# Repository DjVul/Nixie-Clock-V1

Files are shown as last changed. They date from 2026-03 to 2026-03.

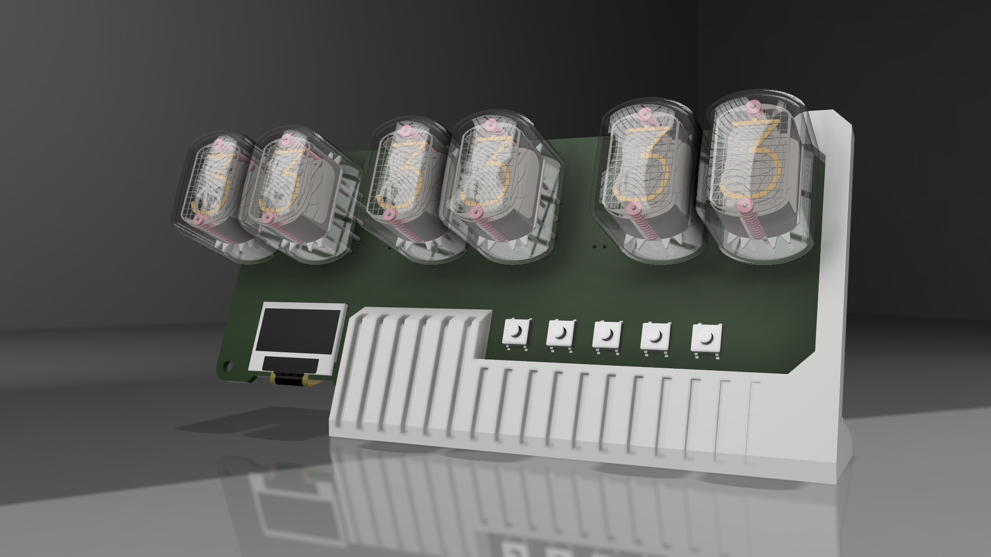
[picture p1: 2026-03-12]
3D Model/Nixie_Clock_V1 v4.png

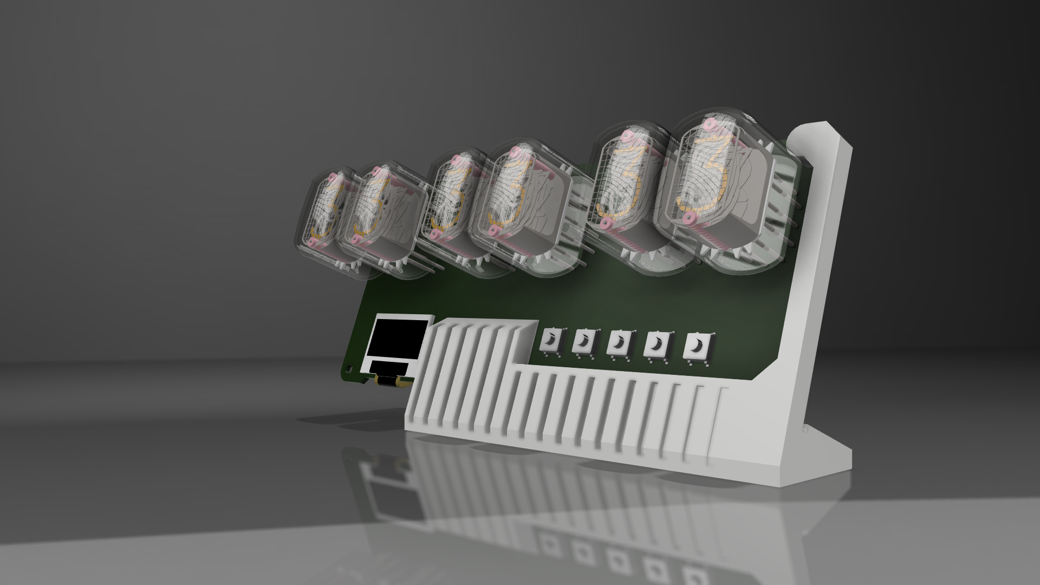
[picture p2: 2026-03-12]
3D Model/Nixie_Clock_V1_FrontRight.png

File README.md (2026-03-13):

# Nixie-Clock-V1

<p align="center">
  IN-12 Nixie Tube Clock
</p>

<p align="center">
  <em>6-digit IN-12 Nixie tube clock with OLED interface</em>
</p>

<p>This repository contains the hardware design and firmware resources for a <strong>6-digit IN-12 Nixie tube clock</strong>. The device is powered via <strong>USB Type-C</strong> and uses a <strong>flyback converter</strong> to generate the high voltage required to drive the Nixie tubes.</p>

<p>The clock features an <strong>OLED display</strong> for a graphical user interface, an onboard <strong>buzzer</strong> for alarms and notifications, and a <strong>DS3231 RTC</strong> backed by a <strong>CR1220 coin cell</strong> to keep accurate time when USB power is off. Control is handled by an <strong>STM32L0 series microcontroller</strong>, providing low-power operation with precise timing and flexible firmware updates.</p>

<p>The goal of this repository is to provide all the files required to reproduce, manufacture, and program the clock. It is intended for <strong>electronics enthusiasts, hobbyists, and developers</strong> interested in Nixie tube technology, high-voltage power design, and custom hardware projects.</p>

<h2>Features</h2>
<ul>
  <li><strong>6-digit IN-12 Nixie tube display</strong></li>
  <li><strong>Low-profile design</strong></li>
  <li><strong>USB-C powered</strong></li>
  <li><strong>Integrated flyback converter</strong> for Nixie high-voltage generation</li>
  <li><strong>OLED display</strong> for graphical user interface</li>
  <li><strong>Onboard buzzer</strong> for alarms and notifications</li>
  <li><strong>DS3231 RTC</strong> with <strong>CR1220 battery backup</strong></li>
  <li><strong>STM32L0 series microcontroller</strong> for control logic</li>
</ul>

<h2>Hardware Overview</h2>
<ul>
  <li><strong>Power Supply:</strong> USB Type-C input with integrated flyback converter</li>
  <li><strong>Display:</strong> OLED graphical interface for settings and status</li>
  <li><strong>Timekeeping:</strong> DS3231 RTC with CR1220 coin cell backup</li>
  <li><strong>Control:</strong> STM32L0 series MCU for low-power operation</li>
  <li><strong>Buzzer:</strong> Onboard for alarms and notification feedback</li>
  <li><strong>PCB:</strong> Low-profile design with full schematics and Gerber files</li>
</ul>

<h2>Repository Contents</h2>
<ul>
  <li><strong>Altium Designer project</strong> – complete PCB design files</li>
  <li><strong>Schematics</strong> – circuit diagrams of the system</li>
  <li><strong>Gerber files</strong> – ready for PCB manufacturing</li>
  <li><strong>Firmware binary</strong> – compiled file for programming the microcontroller (soon to be available)</li>
</ul>

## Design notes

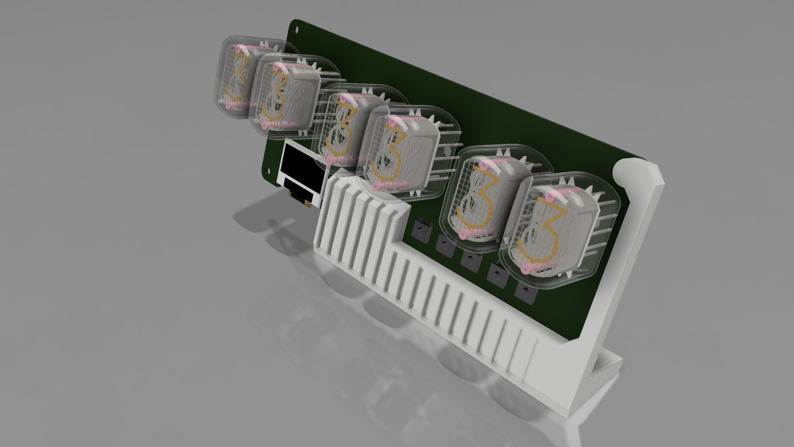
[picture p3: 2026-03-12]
3D Model/Nixie_Clock_V1_FrontRightTop.png

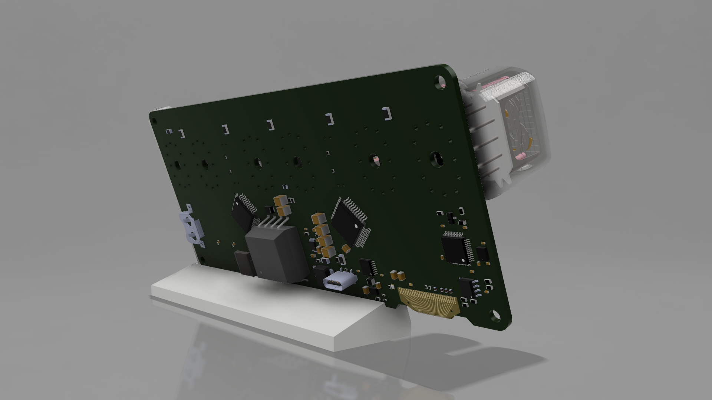
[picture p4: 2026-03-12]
3D Model/Nixie_Clock_V1_back.png

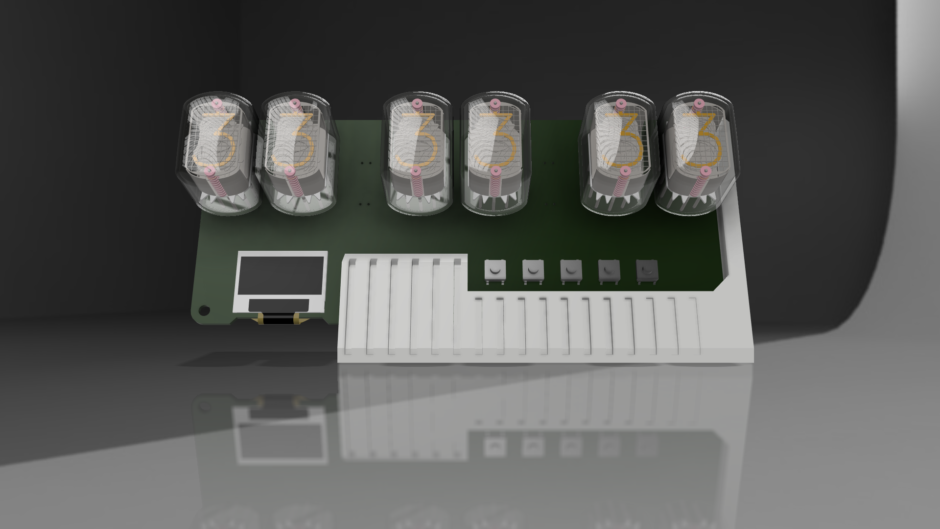
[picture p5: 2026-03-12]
3D Model/Nixie_Clock_V1_Front.png

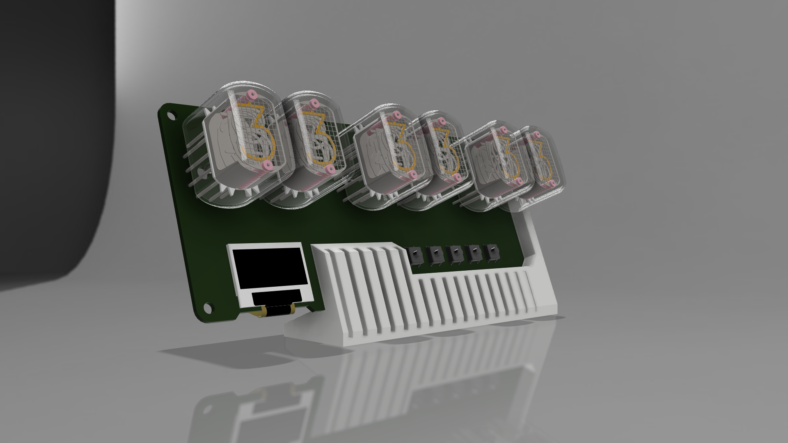
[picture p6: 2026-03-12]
3D Model/Nixie_Clock_V1_FrontLeft.png

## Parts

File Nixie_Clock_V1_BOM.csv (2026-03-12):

Comment | Description | Designator | Footprint | Quantity | Manufacturer Part Number | Manufacturer | Supplier 1
1056 | BATTERY HOLDER COIN 12.5MM SMD | BT1 | 1056 | 1 | 1056 | Keystone | DigiKey
EMK325BJ476MM-T | Multilayer Ceramic Capacitors (High dielectric type), 16V, 47 uF, ± 20 %, 1210, X5R, RoHS | C1, C2, C3, C4 | EMK325BJ476MM-T | 4 | EMK325BJ476MM-T | Taiyo Yuden | Digikey
C2012X6S1C156M125AC | Cap Ceramic 15uF 16V X6S 20% SMD 0805 105°C Blister Plastic T/R | C5, C12, C13 | C2012X6S1C156M125AC | 3 | C2012X6S1C156M125AC | TDK | Digikey
C3216X7T2E224K160AA | CAP CER 0.22UF 250V X7T 1206 | C6, C7 | C3216X7T2E224K160AA | 2 | C3216X7T2E224K160AA | TDK | Digikey
GCM155R71C104KA55D | 0402 0.1 uF 16 V ±10 % Tolerance X7R Surface Mount Multilayer Ceramic Capacitor | C8, C14, C15, C37 | GCM155R71C104KA55D | 4 | GCM155R71C104KA55D | Murata | Digikey
CC0603KRX7R9BB101 | CAP CER 100PF 50V X7R 0603 | C9 | CC0603KRX7R9BB101 | 1 | CC0603KRX7R9BB101 | Yageo | Digikey
AC0603KRX7R9BB103 | CAP CER 10000PF 50V X7R 0603 | C10 | AC0603KRX7R9BB103 | 1 | AC0603KRX7R9BB103 | Yageo | Digikey
CC0603KRX7R9BB223 | CAP CER 0.022UF 50V X7R 0603 | C11 | CC0603KRX7R9BB223 | 1 | CC0603KRX7R9BB223 | Yageo | Digikey
CL05A104KA5NNNC | Multilayer Ceramic Capacitor, 0.1 uF, 25 V, ± 10%, X5R, 0402 [1005 Metric] | C16, C17, C18, C19, C20, C36 | CL05A104KA5NNNC | 6 | CL05A104KA5NNNC | Samsung | Digikey
CC0402CRNPO9BN8R0 | Surface Mount Ceramic Multilayer Capacitor 8pF 0.25pF C0G 50V 0402 Paper T/R | C21, C22 | CC0402CRNPO9BN8R0 | 2 | CC0402CRNPO9BN8R0 | Yageo | Digi-Key
CL21A106KOQNNNE | Multilayer Ceramic Capacitor, 10 uF, 16 V, ± 10%, X5R, 0805 [2012 Metric] | C23, C29, C30 | CL21A106KOQNNNE | 3 | CL21A106KOQNNNE | Samsung | Digikey
GRM188R60J226MEA0J | Multilayer Ceramic Capacitor, 22 uF, 6.3 V, ï¿½ 20%, X5R, 0603 [1608 Metric] | C24 | GRM188R60J226MEA0J | 1 | GRM188R60J226MEA0J | Murata | Digikey
GRM155R61E225ME15D | Multilayer Ceramic Capacitor, 2.2 uF, 25 V, ± 20%, X5R, 0402 [1005 Metric] | C25, C26, C27, C28 | GRM155R61E225ME15D | 4 | GRM155R61E225ME15D | Murata | Digikey
CBR04C101F3GAC | Multilayer Ceramic Capacitor, 100 pF, 25 V, ± 1%, C0G (NP0), 0402 [1005 Metric] | C31, C32, C33, C34, C35 | CBR04C101F3GAC | 5 | CBR04C101F3GAC | KEMET | Digikey
RFN1LAM6STR | DIODE STANDARD 600V 800MA PMDTM | D1 | RFN1LAM6STR | 1 | RFN1LAM6STR | Rohm | Digikey
150060VS55040 | WL-SMCD SMT Mono-color Chip LED Diffused | D2 | 150060VS55040 | 1 | 150060VS55040 | Wurth Electronics | Digikey
IN12A | IN12A NIxie Tube | DS1, DS2, DS3, DS4, DS5, DS6 | IN12A | 6
1210L150/16WR | PTC RESET FUSE 16V 1.5A 1210 | F1 | 1210L150/16WR | 1 | 1210L150/16WR | Littelfuse | Digikey
BLM18BD252SN1D | Ferrite Beads Multi-Layer 2.5KOhm 25% 100MHz 50mA 1.5Ohm DCR 0603 T/R | FB1 | BLM18BD252SN1D | 1 | BLM18BD252SN1D | Murata | Digikey
USB4120-03-C | USB Connector, 24 Contact(s), Female, Right Angle, Solder Terminal, Locking, Receptacle | J1 | USB4120-03-C | 1 | USB4120-03-C | Global Connector Technology | Digikey
DFE201612E-R47M=P2 | Inductor Power Shielded Wirewound 0.47uH 20% 1MHz Metal 4.5A 0.026Ohm DCR 0806 T/R | L1 | DFE201612E-R47M=P2 | 1 | DFE201612E-R47M=P2 | Murata | Digikey
CPT-9019S-SMT-TR | BUZZER PIEZO 3V 9X9MM SMD | LS1 | CPT-9019S-SMT-TR | 1 | CPT-9019S-SMT-TR | Same Sky | Digikey
4PMH | Just pads for soldering 4 pin male angled header | P1 | 4PMH | 1
IRLR3110ZTRPBF | MOSFET N-CH 100V 42A DPAK | Q1 | IRLR3110ZTRPBF | 1 | IRLR3110ZTRPBF | Infineon | Digikey
2N7002NXAKR | MOSFET N-CH 60V 190MA TO236AB | Q3 | 2N7002NXAKR | 1 | 2N7002NXAKR | Nexperia | Digikey
RC0603FR-07140KL | SMD Chip Resistor, 140 kOhm, ± 1%, 100 mW, 0603 [1608 Metric], Thick Film, General Purpose | R1, R5 | RC0603FR-07140KL | 2 | RC0603FR-07140KL | Yageo | Digikey
RG2012P-105-B-T5 | RES SMD 1M OHM 0.1% 1/8W 0805 | R2 | RG2012P-105-B-T5 | 1 | RG2012P-105-B-T5 | Susumu | Digikey
RC0603FR-0763K4L | RES 63.4K OHM 1% 1/10W 0603 | R3 | RC0603FR-0763K4L | 1 | RC0603FR-0763K4L | Yageo | Digikey
RC0603FR-0722RL | RES 22 OHM 1% 1/10W 0603 | R4, R42 | RC0603FR-0722RL | 2 | RC0603FR-0722RL | Yageo | Digikey
RC0603FR-0710KL | RES 10K OHM 1% 1/10W 0603 | R6, R8, R11, R36, R37, R38, R39, R40 | RC0603FR-0710KL | 8 | RC0603FR-0710KL | Yageo | Digikey
PE1206FRF470R02L | RES 0.02 OHM 1% 1W 1206 | R7 | PE1206FRF470R02L | 1 | PE1206FRF470R02L | Yageo | Digikey
RC0402FR-075K1L | SMD Chip Resistor, 5.1 kOhm, ï¿½ 1%, 62.5 mW, 0402 [1005 Metric], Thick Film, General Purpose | R9, R10 | RC0402FR-075K1L | 2 | RC0402FR-075K1L | Yageo | Digikey
RC1210FR-0722KL | RES 22K OHM 1% 1/2W 1210 | R12, R13, R14, R15, R16, R17 | RC1210FR-0722KL | 6 | RC1210FR-0722KL | Yageo | Digikey
CRCW04021K20JNED | Res Thick Film 0402 1.2K Ohm 5% 1/16W ±200ppm/°C Molded SMD SMD Paper T/R | R18, R23 | CRCW04021K20JNED | 2 | CRCW04021K20JNED | Vishay Dale | Digikey
RT0402BRE07100KL | Res Thin Film 0402 100K Ohm 0.1% 1/16W ±50ppm/°C Molded SMD Paper T/R | R19, R22, R29, R31, R32, R33, R34, R35 | RT0402BRE07100KL | 8 | RT0402BRE07100KL | Yageo | Digikey
CRCW0402511KFKED | Res Thick Film 0402 511K Ohm 1% 1/16W ±100ppm/°C Molded SMD SMD Paper T/R | R20 | CRCW0402511KFKED | 1 | CRCW0402511KFKED | Vishay | Digikey
RC0603FR-0791KL | SMD Chip Resistor, 91 kOhm, ± 1%, 100 mW, 0603 [1608 Metric], Thick Film, General Purpose | R21 | RC0603FR-0791KL | 1 | RC0603FR-0791KL | Yageo | Digikey
RC0402FR-07390KL | SMD Chip Resistor, 390 kOhm, ± 1%, 63 mW, 0402 [1005 Metric], Thick Film, General Purpose | R30 | RC0402FR-07390KL | 1 | RC0402FR-07390KL | Yageo | Digikey
B3FS-1012P | Switch Tactile N.O. SPST Round Button Gull Wing 24VDC 300000Cycles 150gf SMD Emboss T/R | SW1, SW2, SW3, SW4, SW5 | B3FS-1012P | 5 | B3FS-1012P | Omron | Digikey
750032050 | Trans Powr For LT3751/LT3750 SMD | TR1 | 750032050 | 1 | 750032050 | Wurth Electronics | Digikey
LT3757EMSE#PBF | Boost, Flyback, SEPIC Regulator Positive and Negative Output Step-Up, Step-Up/Step-Down DC-DC Controller IC 10-MSOP-EP | U1 | LT3757EMSE#PBF | 1 | LT3757EMSE#PBF | Analog Devices / Linear Technology | Digikey
HV5122PG-G | IC 32BIT SRL PARALLEL 220V 44PQF | U2, U3 | HV5122PG-G | 2 | HV5122PG-G | Microchip Supertex | Digikey
TXS0104EPWR | IC TRANSLATOR BIDIR 14TSSOP | U4 | TXS0104EPWR | 1 | TXS0104EPWR | Texas Instruments | Digikey
STM32L071CZT6TR | MCU 32-Bit Ultra Low Power STM32L ARM Cortex M0+ RISC 192kB Flash 48-Pin LQFP Tray | U5 | STM32L071CZT6TR | 1 | STM32L071CZT6 | STMicroelectronics | Digikey
TPS63802DLAR | Conv DC to DC Single Boost/Buck-Boost/Buck 1.3V to 5.5V 10-Pin VSON-HR T/R | U6 | TPS63802DLAR | 1 | TPS63802DLAR | Texas Instruments | Digikey
VG-2864KSWEG01 | SSD1306 0.96 OLED Display ROHS | U7 | VG-2864KSWEG01 | 1 | VG-2864KSWEG01 | WiseChip | www.lcsc.com
DS3231MZ+TRL | IC RTC CLK/CALENDAR I2C 8SOIC | U8 | DS3231MZ+TRL | 1 | DS3231MZ+TRL | Maxim | Digikey
CG04874-8M | Crystal 8.0000MHZ 8PF SMD | X1 | CG04874-8M | 1 | CG04874-8M | NDK | Digi-Key

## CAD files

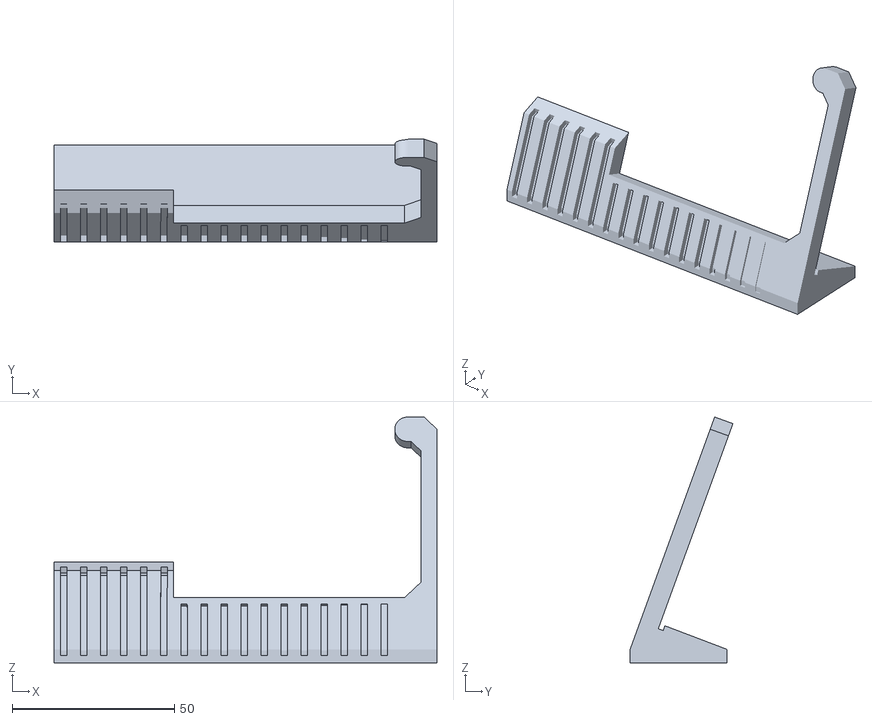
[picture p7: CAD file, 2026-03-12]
NixieStand_V1.stl
117.9 x 31.7 x 75.7

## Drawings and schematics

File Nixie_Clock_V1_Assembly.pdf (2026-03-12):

# 3D Views

# Nixie_Clock_V1 - Assembly Documentation

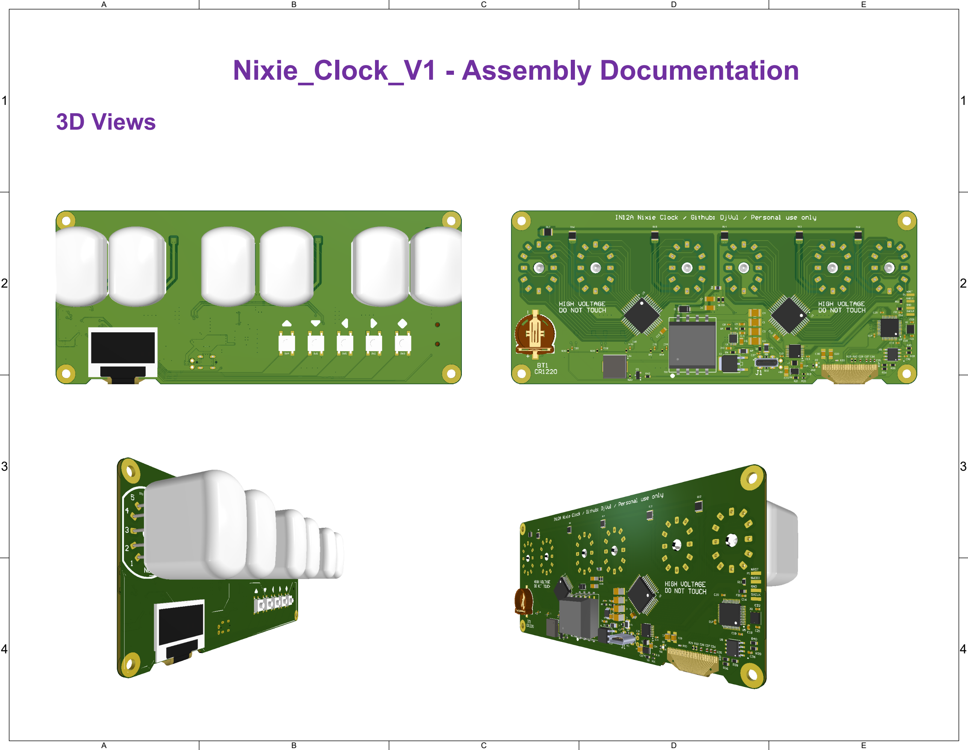
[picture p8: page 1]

A

B

C

D

E

1 | 1
2 | 2
3 | 3
4 | 4

# Isometric Views

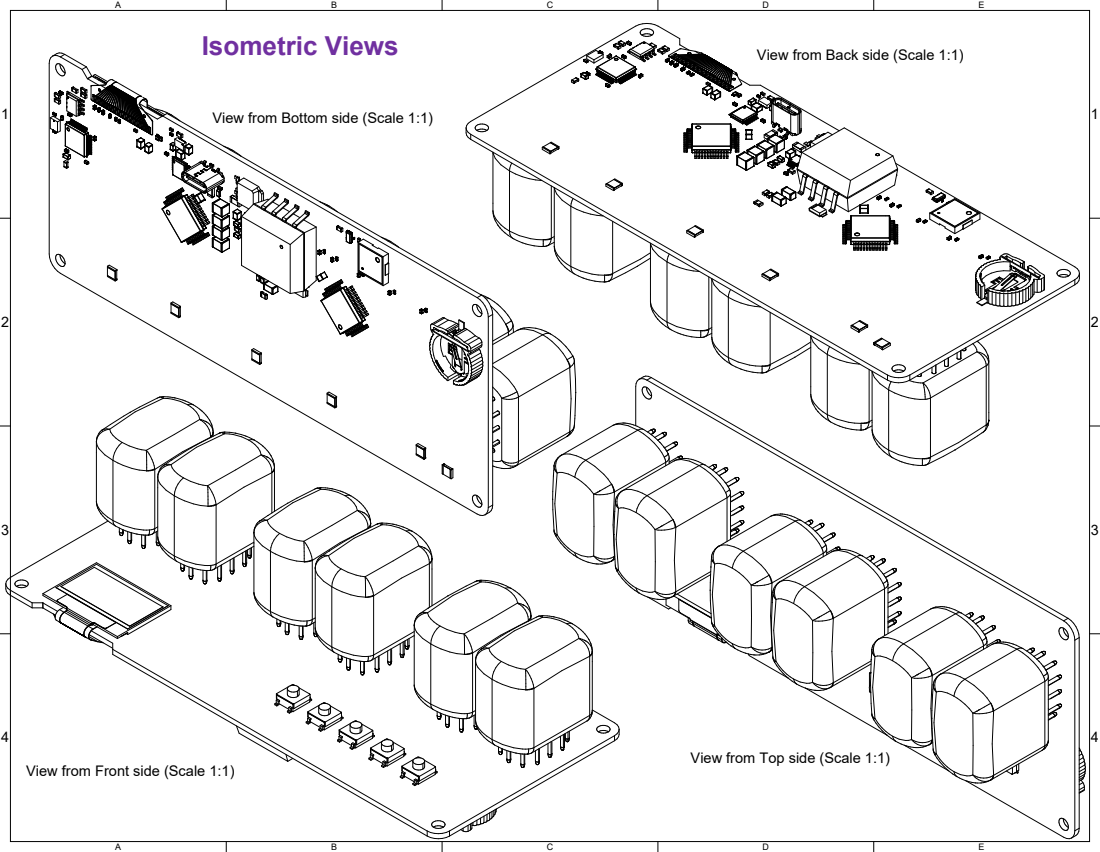
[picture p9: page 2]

View from Back side (Scale 1:1)

View from Bottom side (Scale 1:1)

View from Top side (Scale 1:1)

View from Front side (Scale 1:1)

# Assembly Bottom

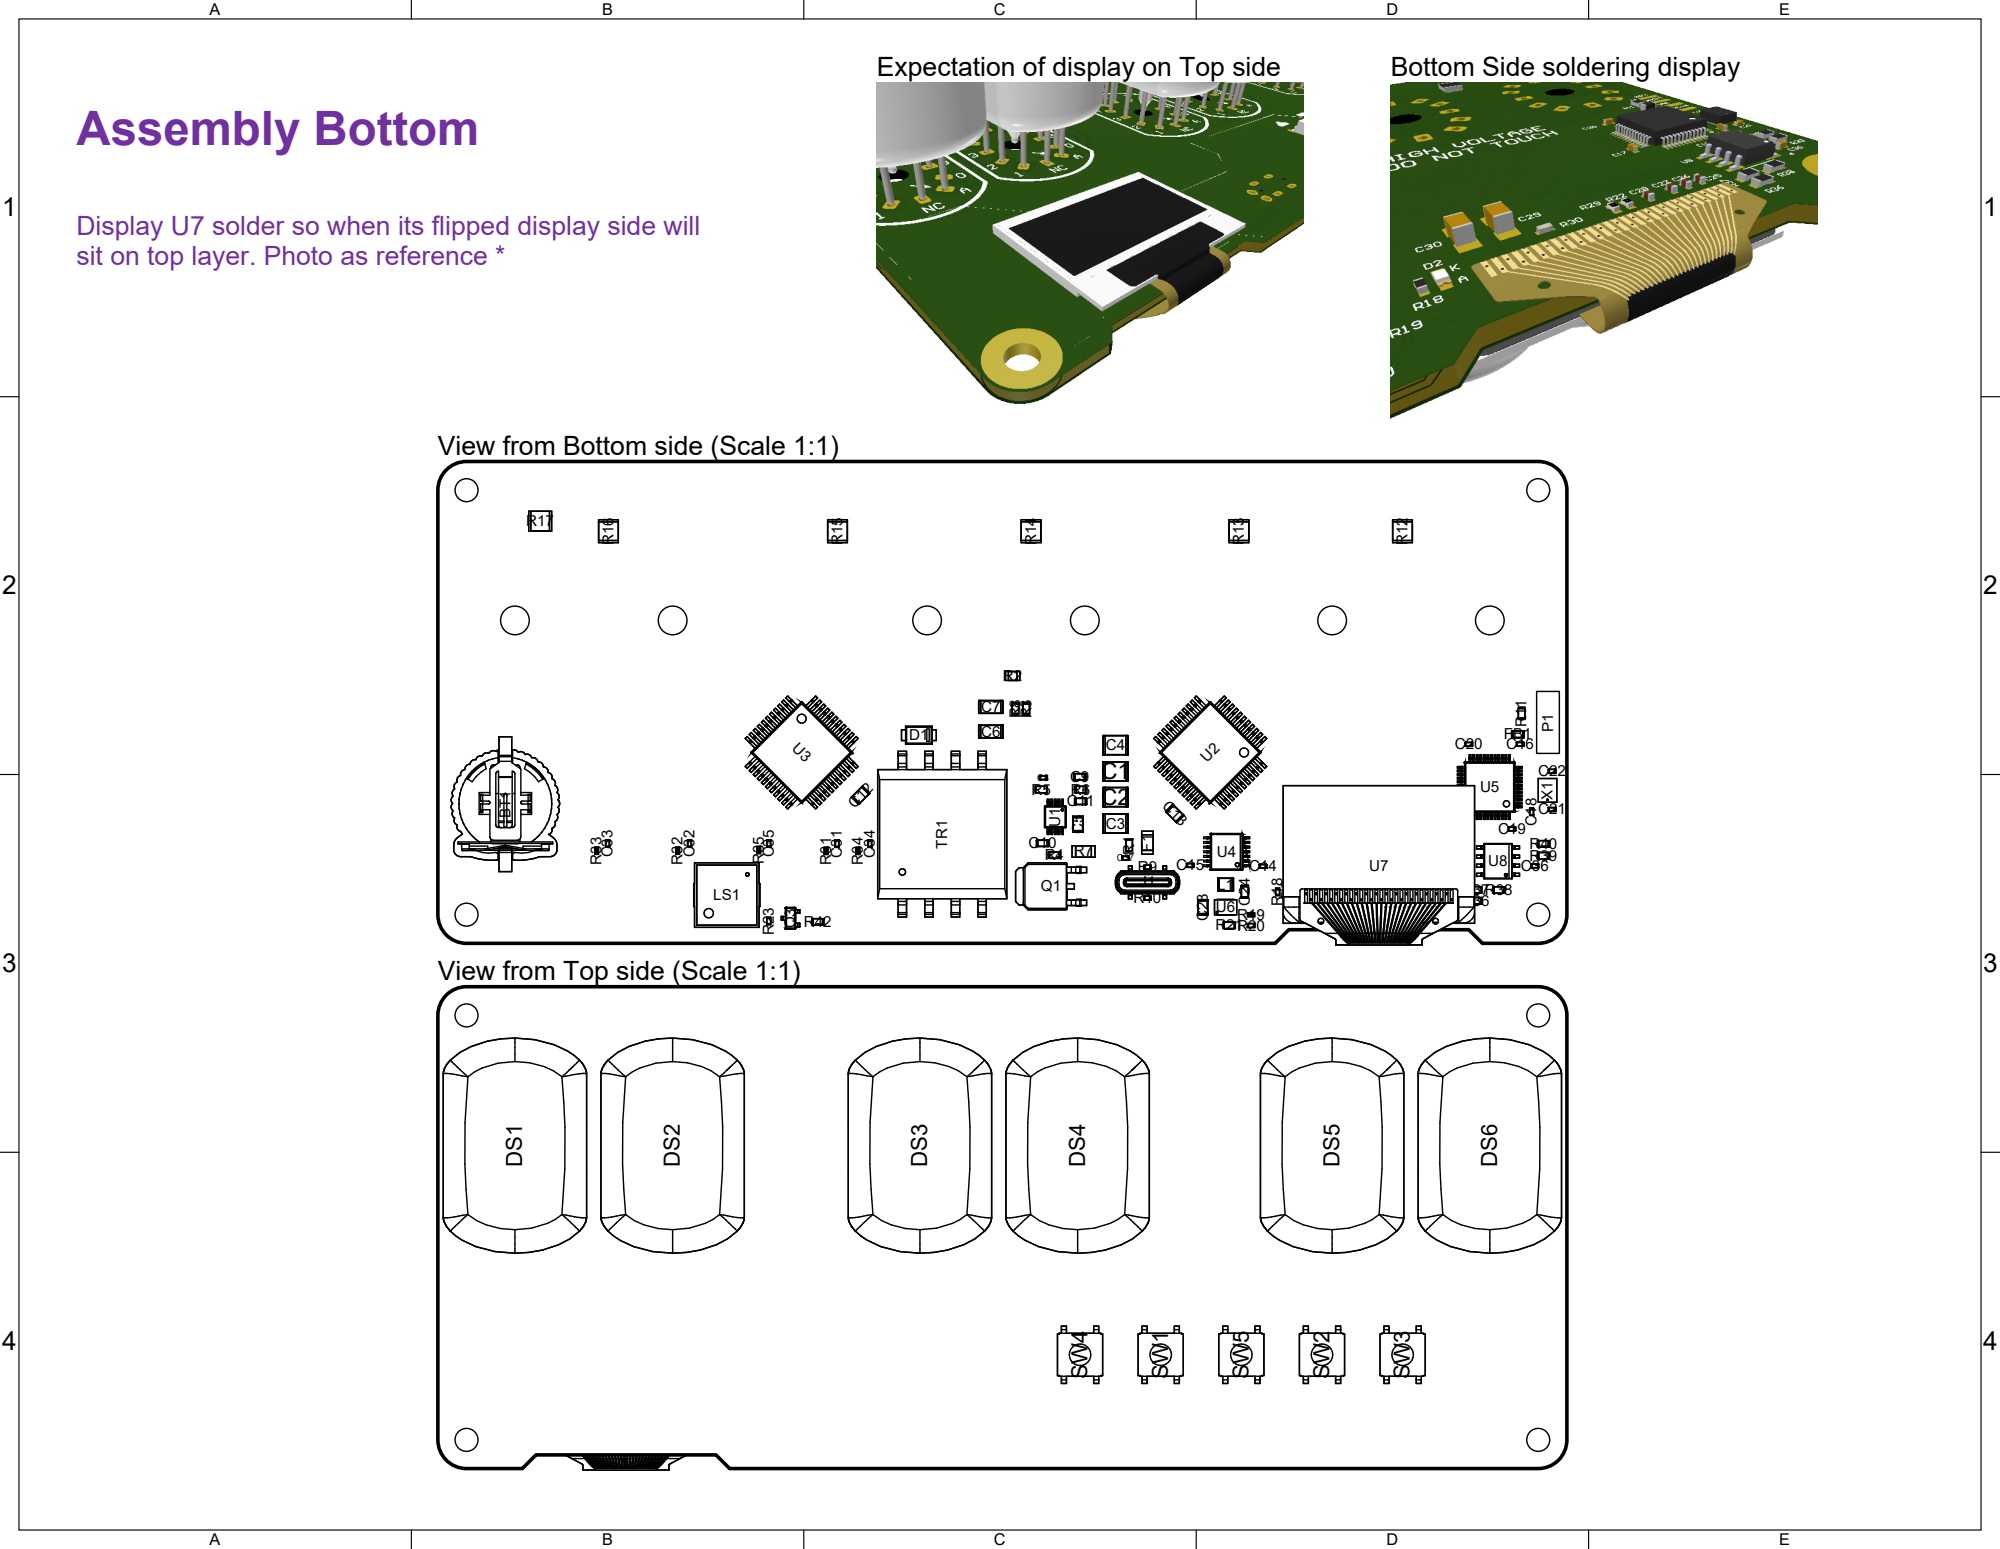
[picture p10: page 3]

Display U7 solder so when its flipped display side will
sit on top layer. Photo as reference *

View from Bottom side (Scale 1:1)

View from Top side (Scale 1:1)

1 | 1
2 | 2
3 | 3
4 | 4

# Layer Stack Legend

# Use common 2 Layer PCBWAY Stackup 1Oz 1.6mm

Material | Layer | Thickness Dielectric Material Type | Gerber
| Top Overlay | | Legend | GTO
Surface Material Top Solder | 0.01mm | Solder Resist | Solder Mask GTS
Copper | Top Layer | 0.04mm | Signal | GTL
Core | 1.50mm | FR-4 | Dielectric
Copper | Bottom Layer | 0.04mm | Signal | GBL
Surface Material Bottom Solder 0.01mm | Solder Resist | Solder Mask GBS
| Bottom Overlay | | Legend | GBO
Total thickness: 1.60mm

Layer Stack Legend

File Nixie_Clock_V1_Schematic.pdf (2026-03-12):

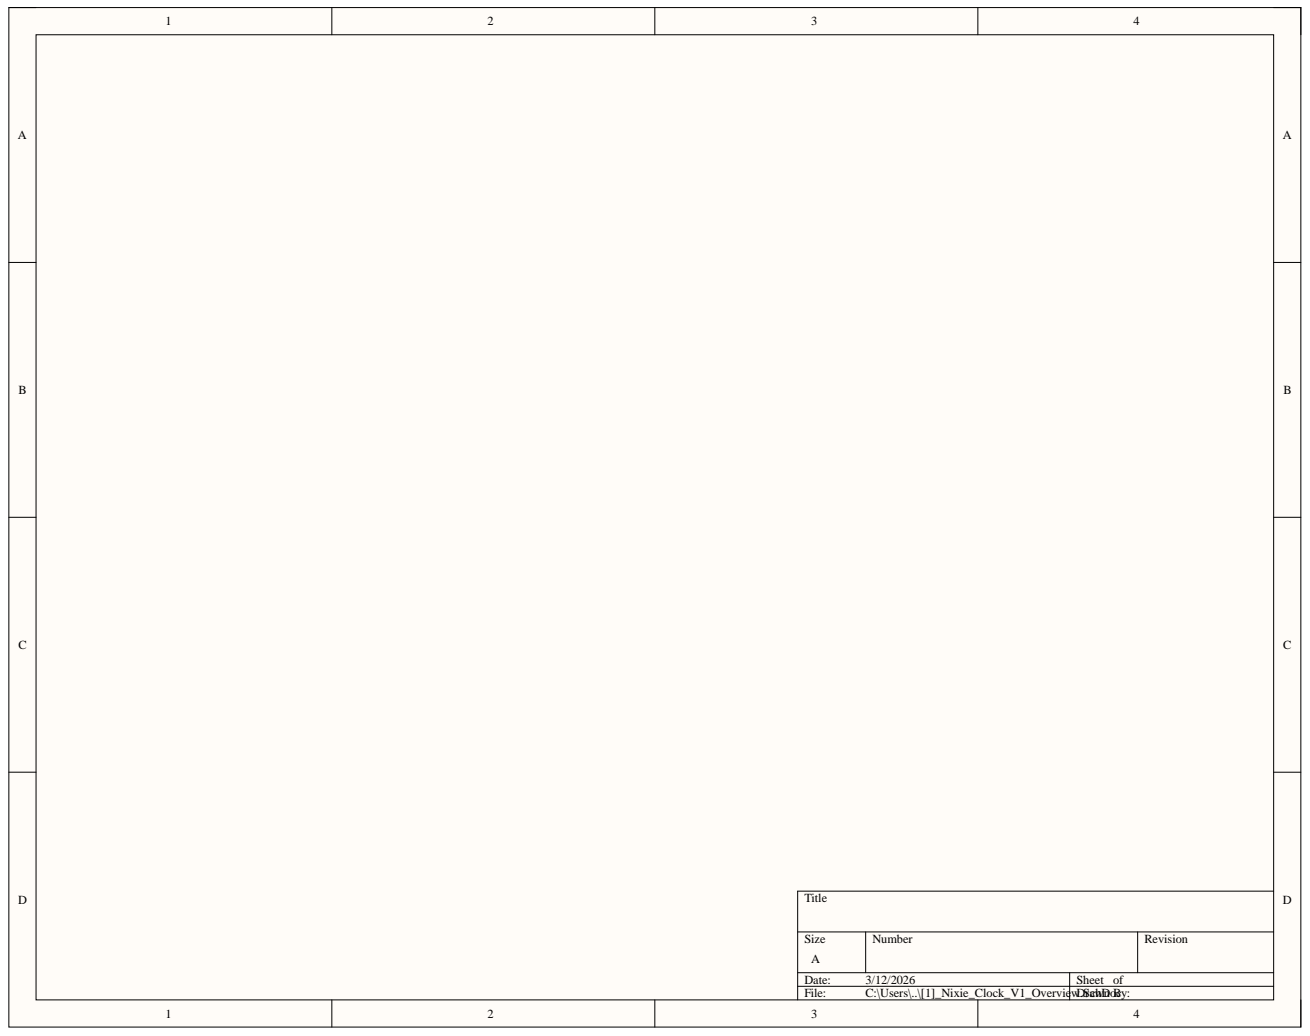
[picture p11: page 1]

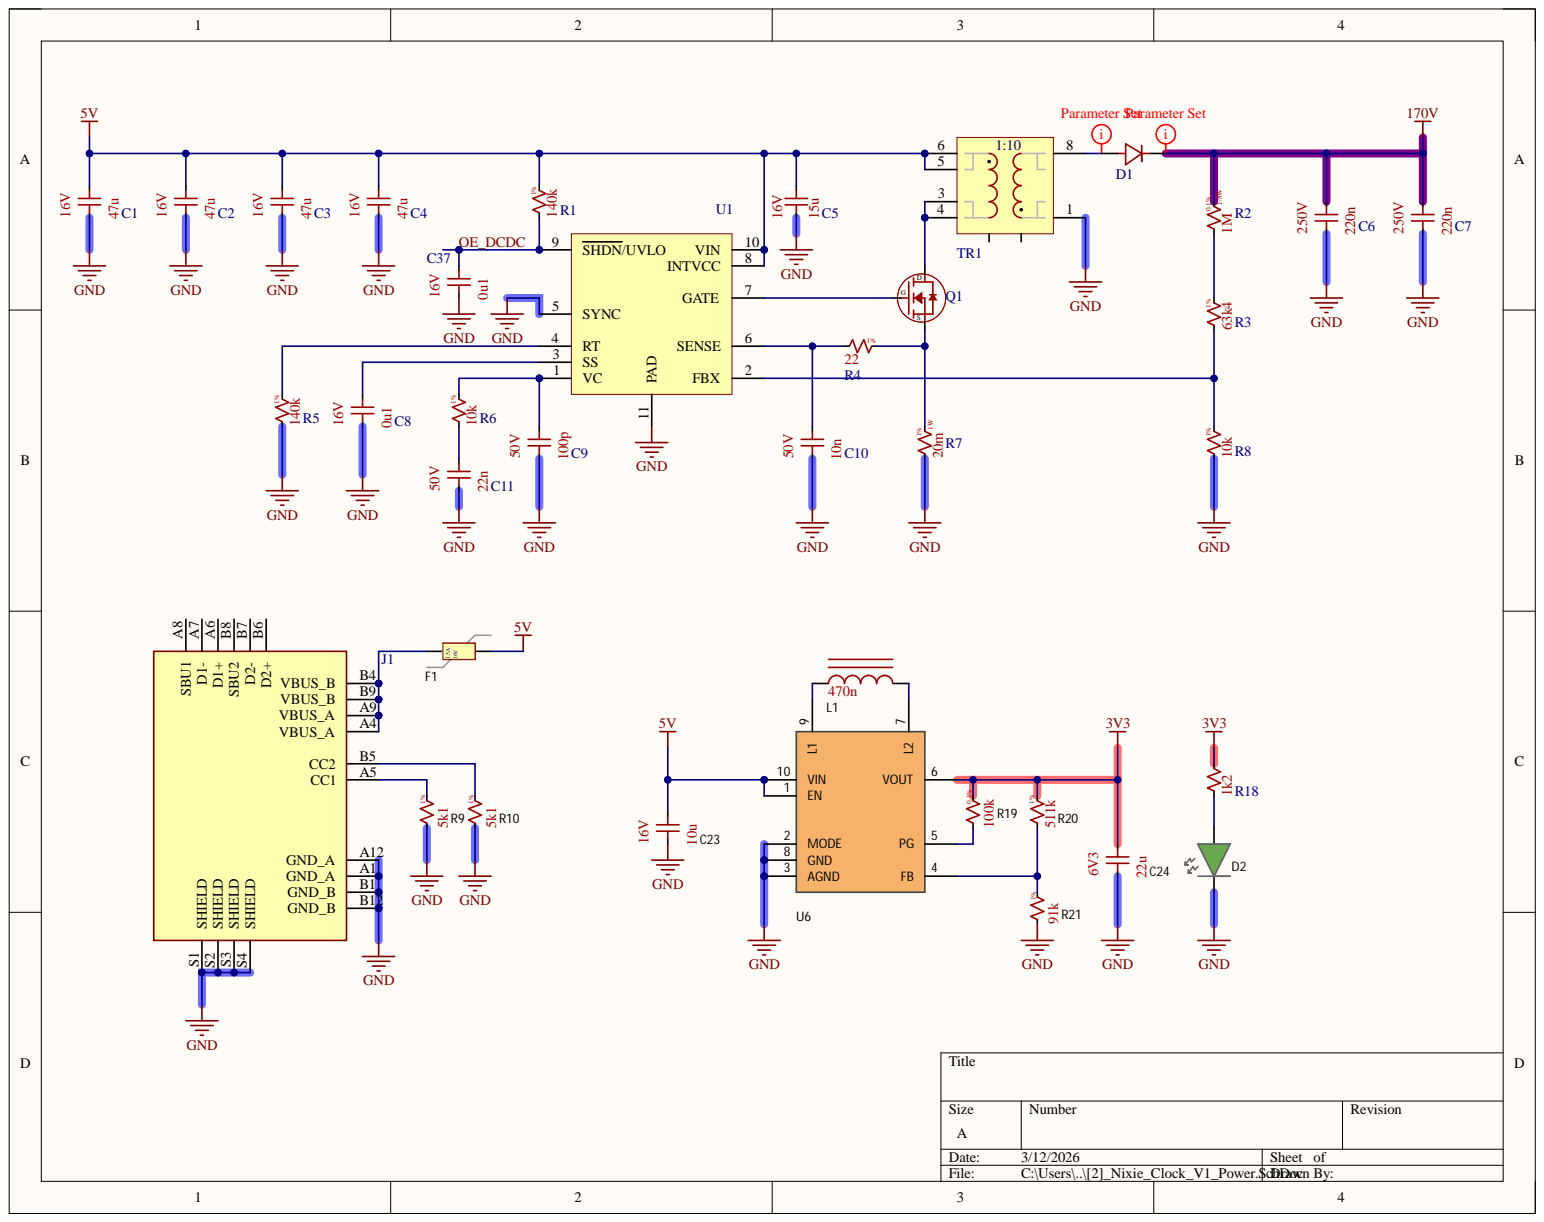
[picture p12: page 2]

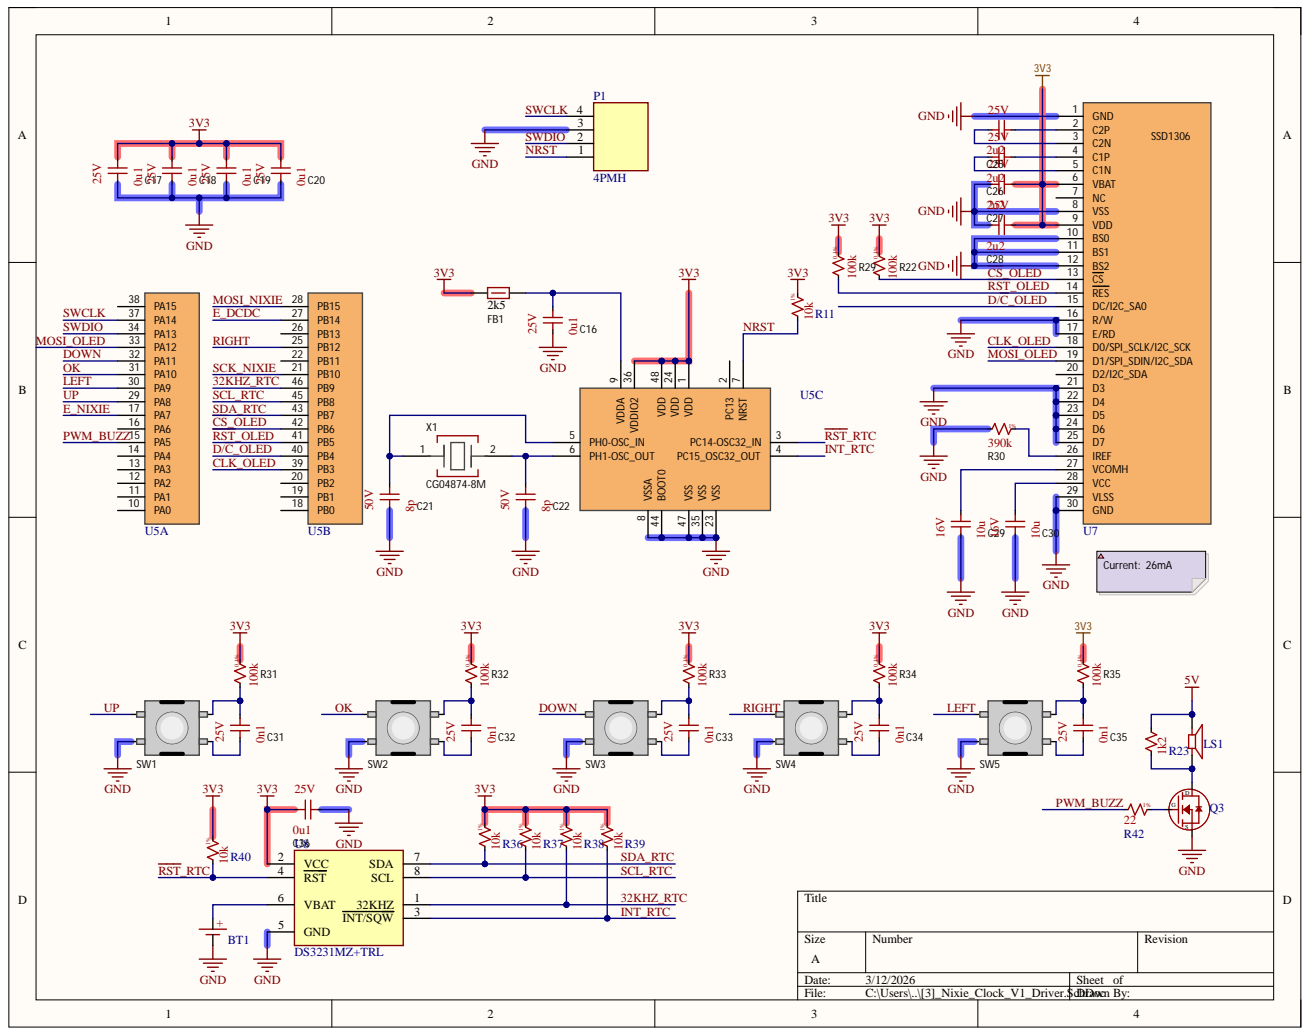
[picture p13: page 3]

2u2
C28

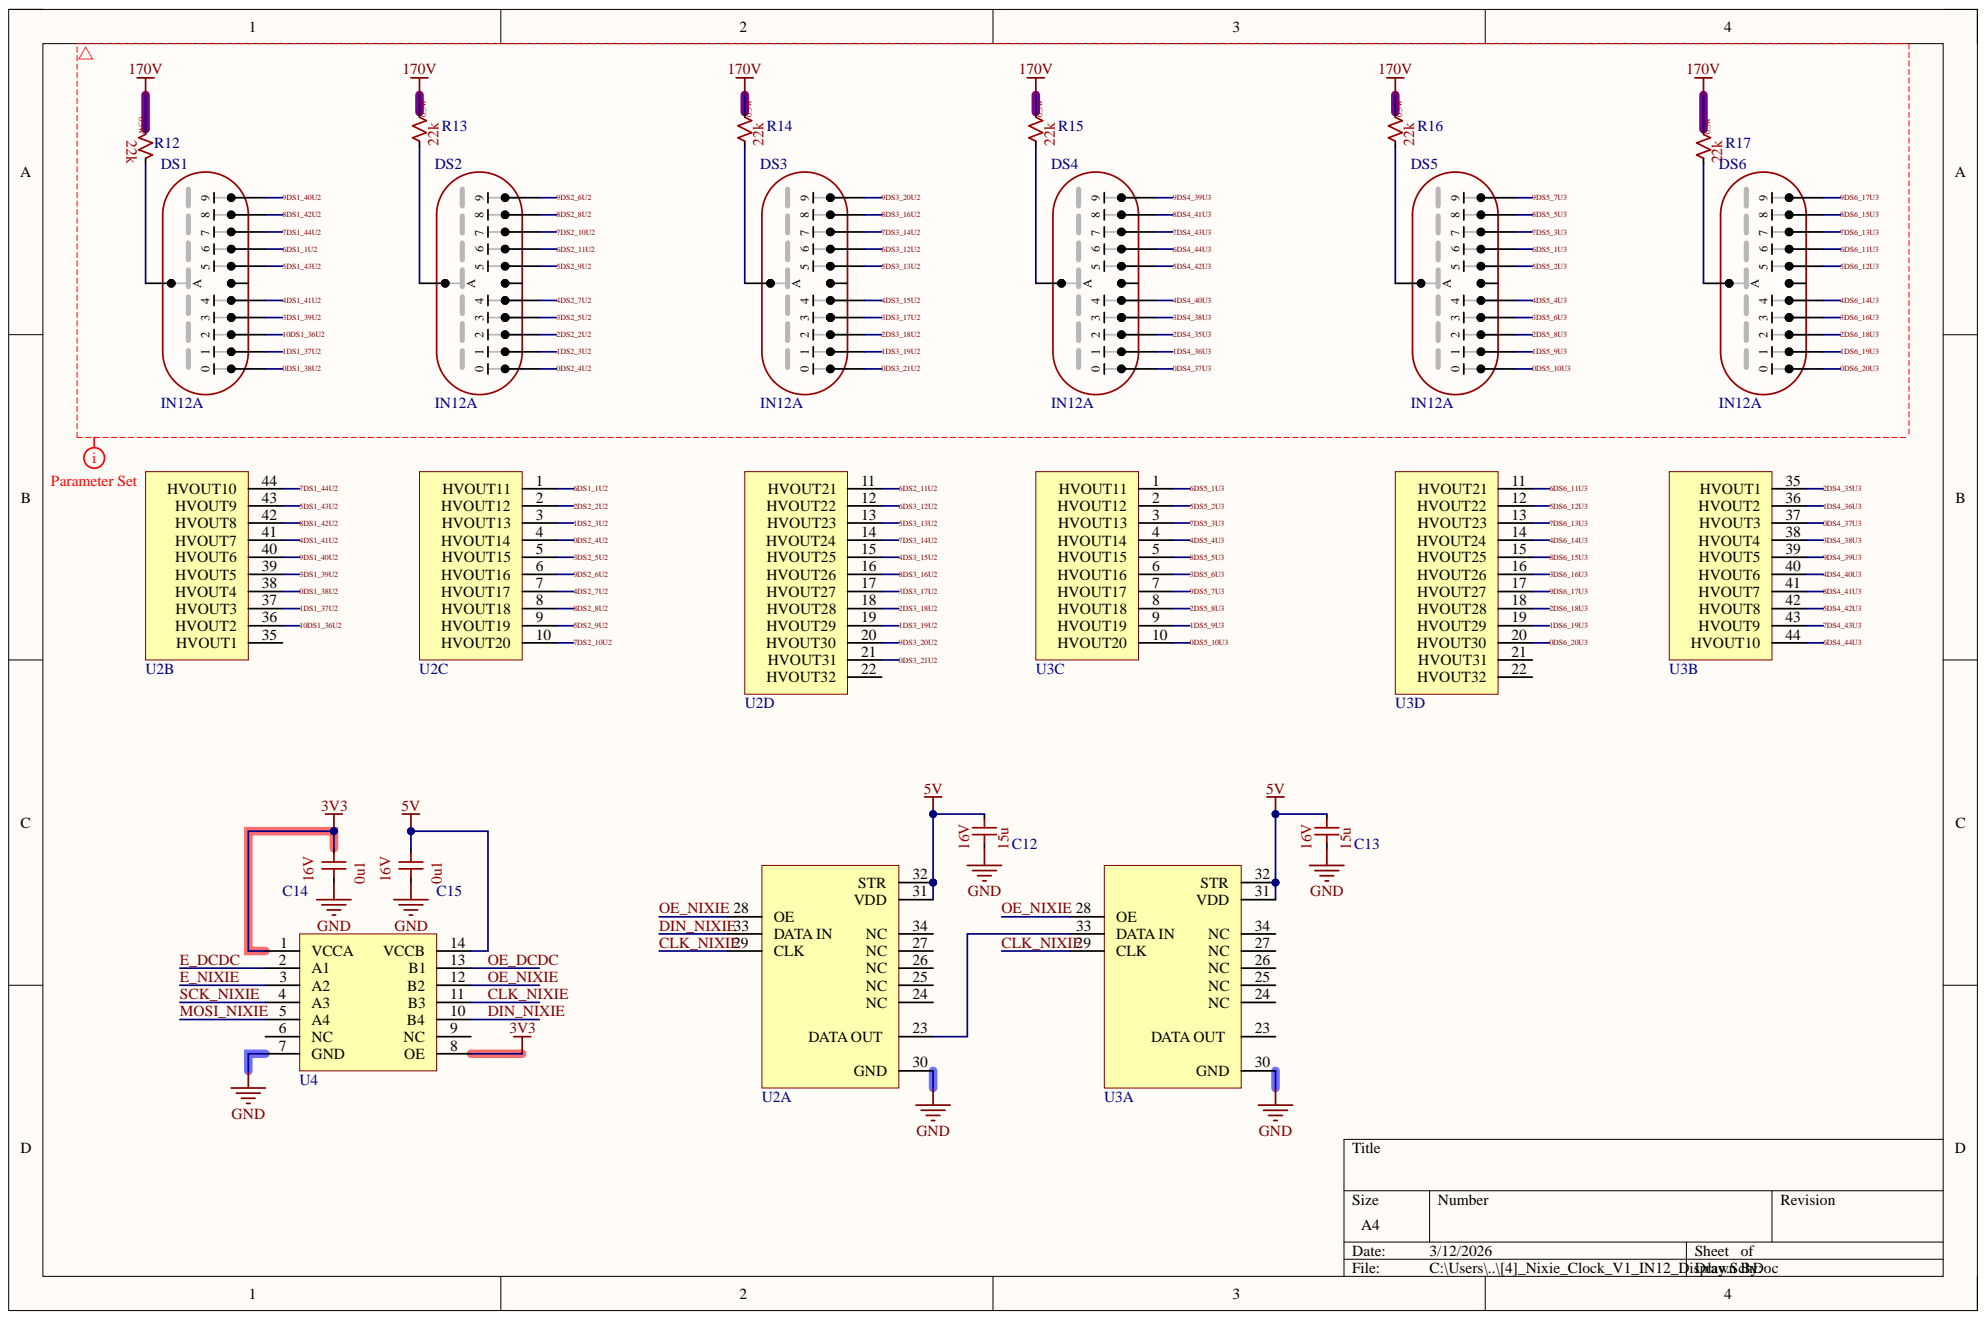
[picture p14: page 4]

Size A4 | Number | Revision

Date: 3/12/2026 | Sheet of
File: C:\Users\..\[4]_Nixie_Clock_V1_IN12_Display Drwn By .SchD:oc
